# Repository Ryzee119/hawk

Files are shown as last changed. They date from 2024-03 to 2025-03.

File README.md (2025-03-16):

## Hawk - Open Source Xbox Live Communicator

This project is an open source replacement of the [Microsoft Xbox Live Communicator](https://xbox.fandom.com/wiki/Xbox_LIVE_Headset) utilizing modern components and custom open-source firmware.

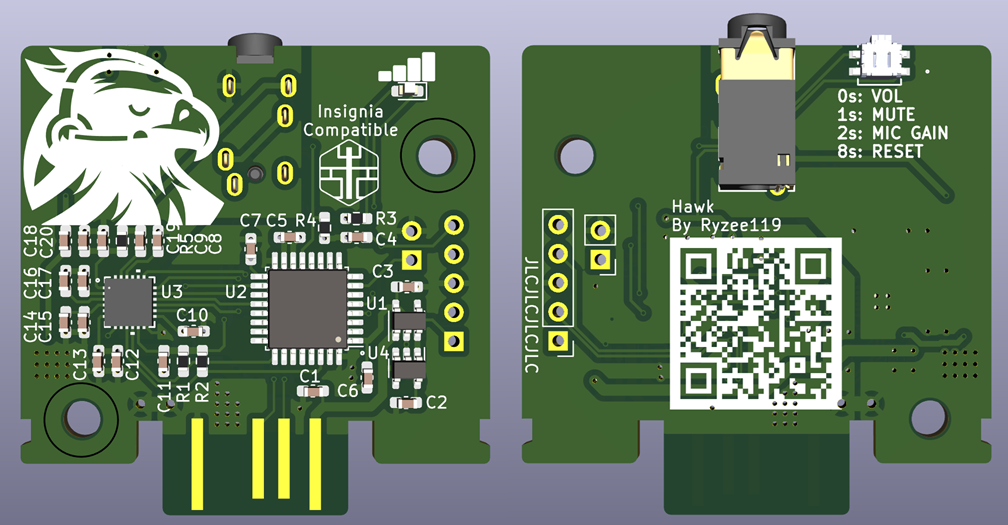
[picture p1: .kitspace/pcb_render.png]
hawk!


It provides feature parity with the original communicator with the following differences:
* A 3.5mm TRRS jack is used to support more generic headsets. (Stereo headsets will output as mono.)
* The volume wheel is replaced with a button. Volume is indicated by LED brightness.

### Usage
* When installing Hawk into your controller, it must be installed in the slot closest to you.
* Press the button to increment the volume. Once maximum volume is reached, it will cycle back to zero.
* Hold the button for 1 second to mute and disable the microphone input (LED will flash at 1Hz).
* Hold the button 2 seconds to enter microphone gain adjustment mode (LED will flash at 4Hz).
* Volume and microphone gain adjustments will be saved internally. You can reset these to default by holding the button down for 8 seconds.

### Assembly
* **When ordering PCB thickness should be 1.2mm!**
* See [Kitspace](https://master.staging.kitspace.dev/Ryzee119/hawk) for BOM, PCB ordering and assembly information.
* See [KiCanvas](https://kicanvas.org/?github=https%3A%2F%2Fgithub.com%2FRyzee119%2Fhawk%2Ftree%2Fmaster%2Fhardware) for schematic view.
* See [Tracespace](https://tracespace.io/view/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) for Gerber view.

### Compilation
* Download and install [Visual Studio Code](https://code.visualstudio.com/).
* Install the [PlatformIO IDE](https://platformio.org/platformio-ide) plugin.
* In Visual Studio Code File > Open Folder... > hawk
* Hit build on the Platform IO toolbar (✓).

### Programming
* [Compile](https://github.com/Ryzee119/hawk?tab=readme-ov-file#compilation) or [Download](https://github.com/Ryzee119/hawk/releases) the pre-built firmware image.
* USB DFU. Connect an xbox controller to your PC, then hold the Hawk button down while inserting it into the controller to enter DFU mode. Your PC should detect this. you can then program with [STM32Cubeprogrammer](https://www.st.com/en/development-tools/stm32cubeprog.html)
* ST-Link interface (5 pin header available on PCB)

### FAQ
* What is the pinout of the headphone jack?
  * Hawk's headphone jack is wired as per [CTIA standard TRRS](https://upload.wikimedia.org/wikipedia/commons/e/ee/3.5mm_TRRS_phone_connector_with_CTIA_standard.png). There is another less common standard called OMTP. This will not work but adapters are available.
* It doesn't fit in my controller slot.
  * PCB should be manufactured with 1.2mm thickness. Most fabrication houses default to 1.6mm so be careful!
* Microphone is really quiet.
  * You can increase the microphone gain above default. Hold the Hawk button down for more than 2 seconds to enter gain adjustment mode. The LED will blink 4 times per second to show it is in the right mode then press the button to increase the gain. Hold for 1 second to exit. If this is still too quiet, you can modify the `MAX_MICROPHONE_GAIN` variable and recompile the code to bump it up even higher.
* Speaker is really quiet
  * Adjust the volume by pressing the button until the LED is at its maximum brightness. Unfortunately, it is already compiled to the maximum allowable by Hawk. If it is still too quiet, your headset's impedance may be too low.
* Does this work on modern controller adapters (ogx360, wingman etc)?
  * Not really, but kind of. To do this, you must connect a USB 1.1 compliant hub to the Xbox player port. Your controller then connects to port 1 of this hub and Hawk to port 2.
* LED just flashes constantly when connected
  * This means the main IC cannot communicate with the audio codec on Hawk. This is likely a soldering issue.
* `Error: Database: There's no active configuration for this device.` when programming.
  * Try an earlier revision of STM32CubeProgrammer. Users have reported some success with `v2.5.0`.

### Attribution
* [Board outline](https://github.com/Zeigren/OXC)
* [EEPROM emulation code](https://github.com/nimaltd/ee)

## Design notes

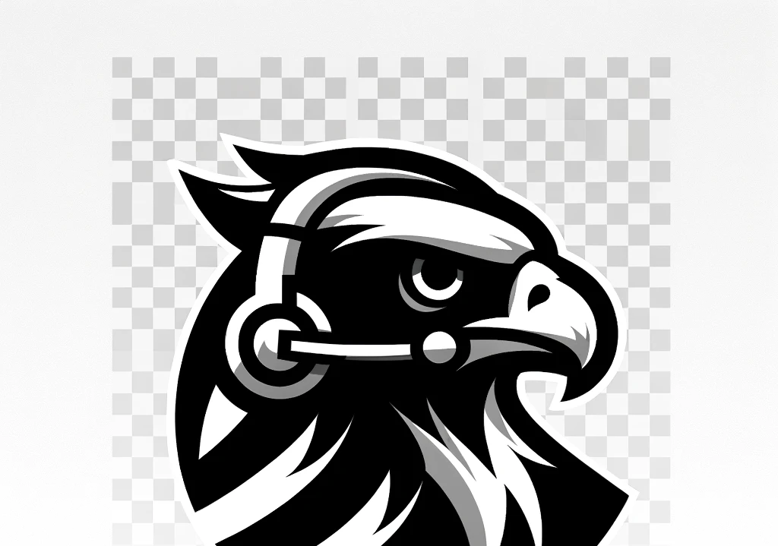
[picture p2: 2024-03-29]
hardware/hawk.bmp

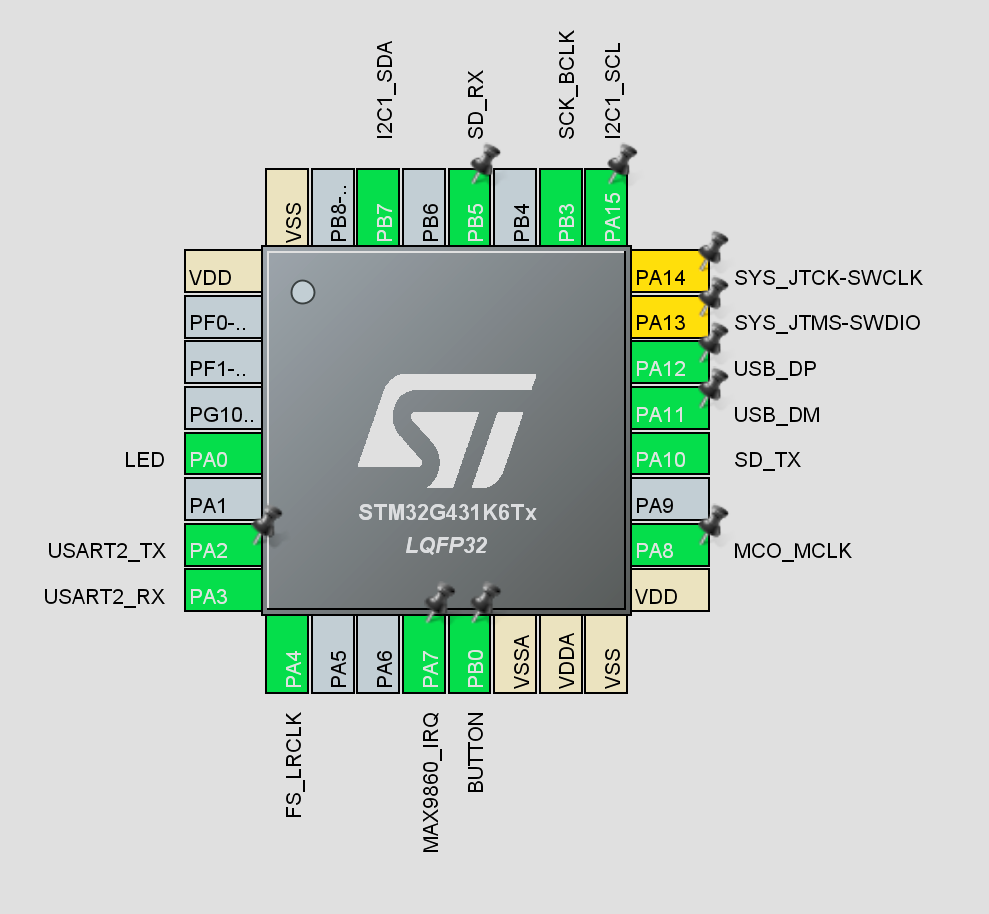
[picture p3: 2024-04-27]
hardware/pinout.png

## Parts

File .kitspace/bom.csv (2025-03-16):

Reference | Qty | Description | Part Number | Manufacturer | Digikey | LCSC
U1 | 1 | IC REG LINEAR 3.3V 300MA SOT23-5 | MIC5504-3.3YM5 | Microchip Technology | 576-4764-1-ND | C3021093
U2 | 1 | IC MCU 32BIT 32KB FLASH 32LQFP | STM32G431K6T6 | STMicroelectronics | 497-STM32G431K6T6-ND | C730097
U3 | 1 | IC CODEC MONO AUD 16BIT 24TQFN | MAX9860ETG+T | Maxim Integrated | MAX9860ETG+TCT-ND | C516787
U4 | 1 | IC REG LINEAR 1.8V 300MA SOT23-5 | MIC5504-1.8YM5 | Microchip Technology | 576-4879-1-ND | C626116
C1, C2, C3, C12, C20 | 5 | CAP CER 10uF 0603 | CAP CER 10uF 0603 | ANY | 311-1448-1-ND | C19702
C4, C5, C6, C7, C13 | 5 | CAP CER 100nF 0603 | CAP CER 100nF 0603 | ANY | 311-1088-1-ND | C30926
C8, C9, C10, C11, C14, C15, C16, C17, C18, C19 | 10 | CAP CER 1uF 0603 | CAP CER 1uF 0603 | ANY | 311-1446-1-ND | C15849
R1, R2, R4, R5 | 4 | RES SMD 1.5K OHM 1% 1/10W 0603 | RES SMD 1.5K OHM 1% 1/10W 0603 | ANY | 118-CR0603-FX-1501ELFCT-ND | C114668
R3 | 1 | RES SMD 150 OHM 1% 1/10W 0603 | RES SMD 150 OHM 1% 1/10W 0603 | ANY | 118-CR0603-FX-1500ELFCT-ND | C114608
D1 | 1 | LED 2V 20MA 0603 | LED 2V 20MA 0603 | ANY | 3147-B1911PG--20D000514U1930CT-ND | C5123548
J3 | 1 | CONN JACK TRRS 3.5MM | 54-00298 | Tensility International Corp | 839-54-00298CT-ND | C707261
SW1 | 1 | SWITCH TACTILE SPST-NO MOM | EVQ-P7J01P | Panasonic Electronic Components | P16767CT-ND | C2828254

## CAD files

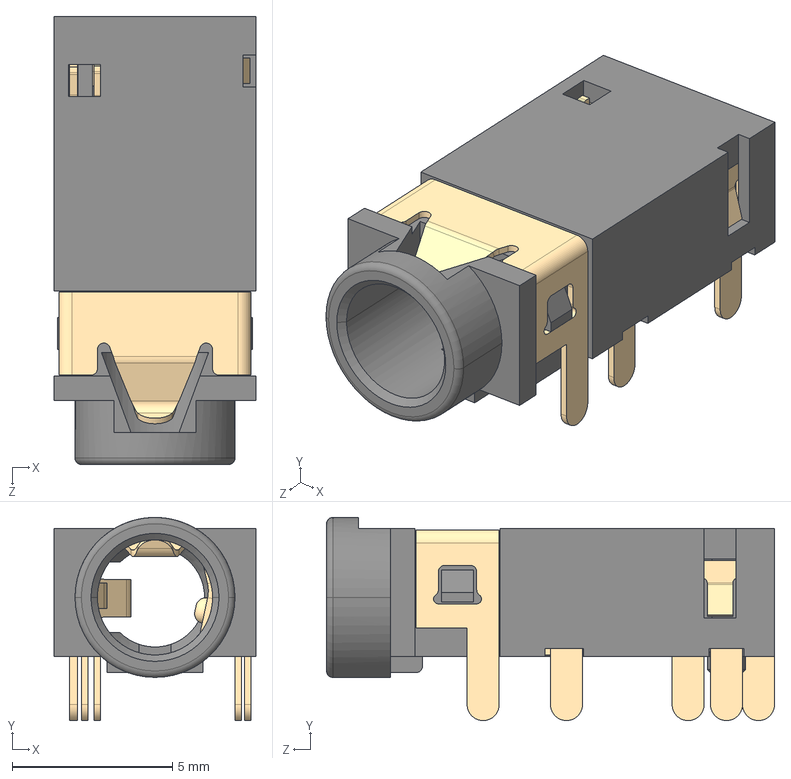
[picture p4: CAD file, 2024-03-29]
hardware/parts/54-00298/54-00298.step
6.30 x 6.35 x 14.0 mm

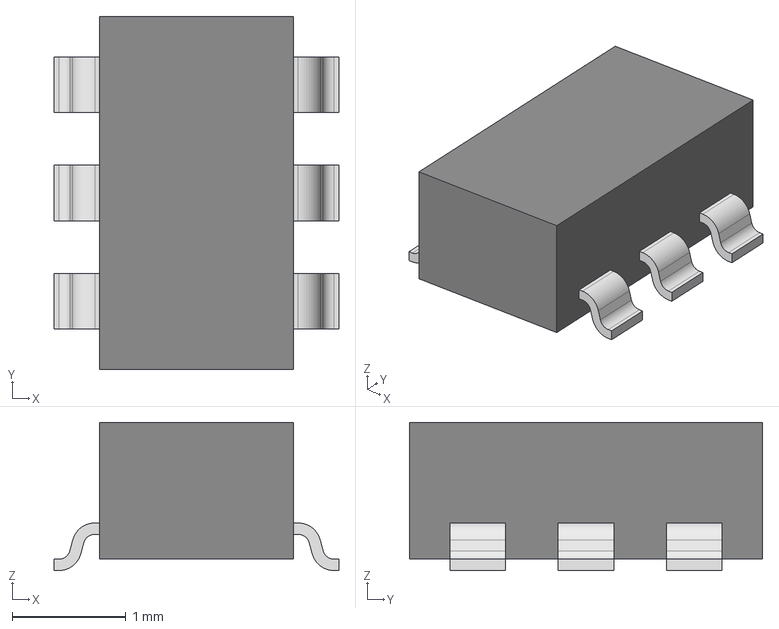
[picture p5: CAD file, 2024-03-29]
hardware/parts/AP7312_1833W6_7/SOT26_DIO.step
2.50 x 3.10 x 1.30 mm

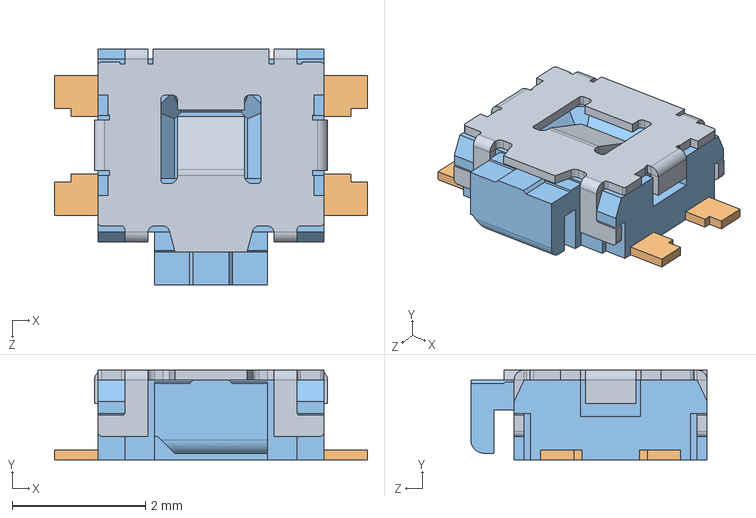
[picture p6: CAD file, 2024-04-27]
hardware/parts/EVQ-P7L01P/EVQ-P7L01P.step
4.70 x 1.35 x 3.55 mm

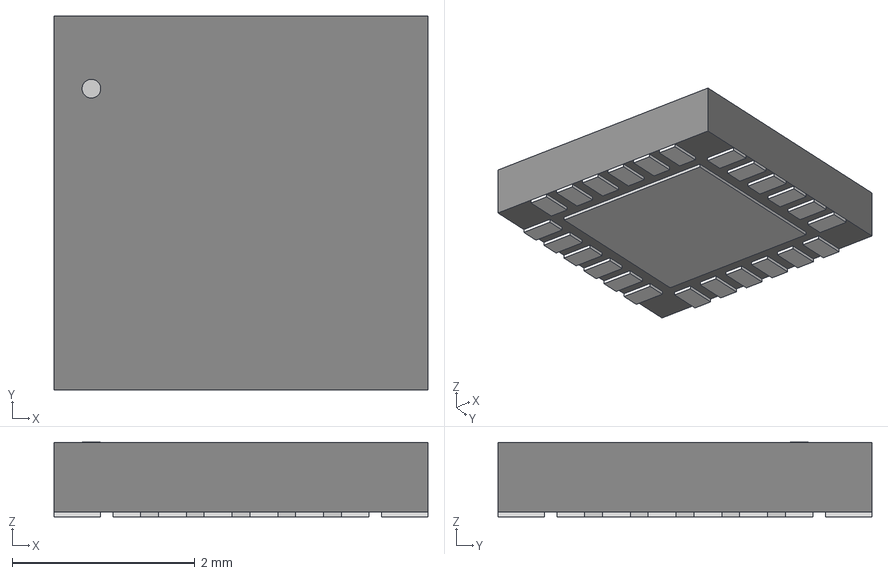
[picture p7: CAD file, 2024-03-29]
hardware/parts/MAX9860ETG_T/21-0139I_T2444-4_MXM.step
4.09 x 4.09 x 0.815 mm

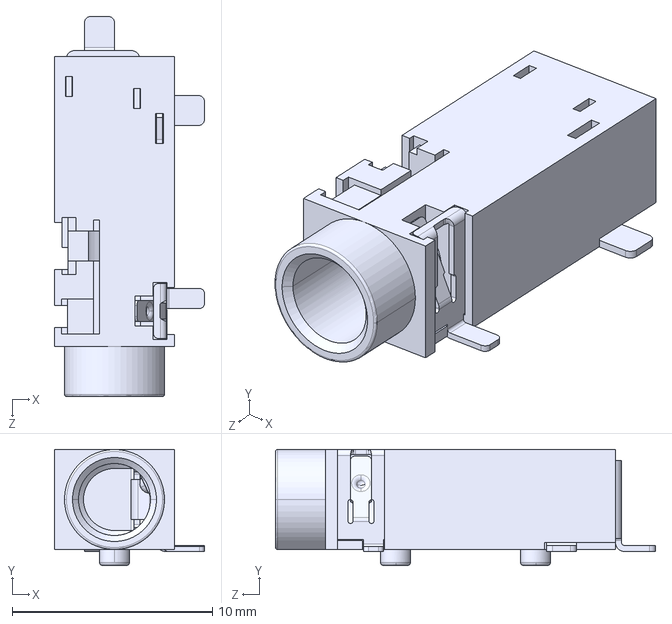
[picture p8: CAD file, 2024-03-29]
hardware/parts/MJ_3523_SMT_TR/CUI_DEVICES_MJ-3523-SMT-TR.step
7.50 x 5.80 x 19.0 mm

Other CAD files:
hardware/parts/EVQ_P7A01P/EVQ-P7A01P.step

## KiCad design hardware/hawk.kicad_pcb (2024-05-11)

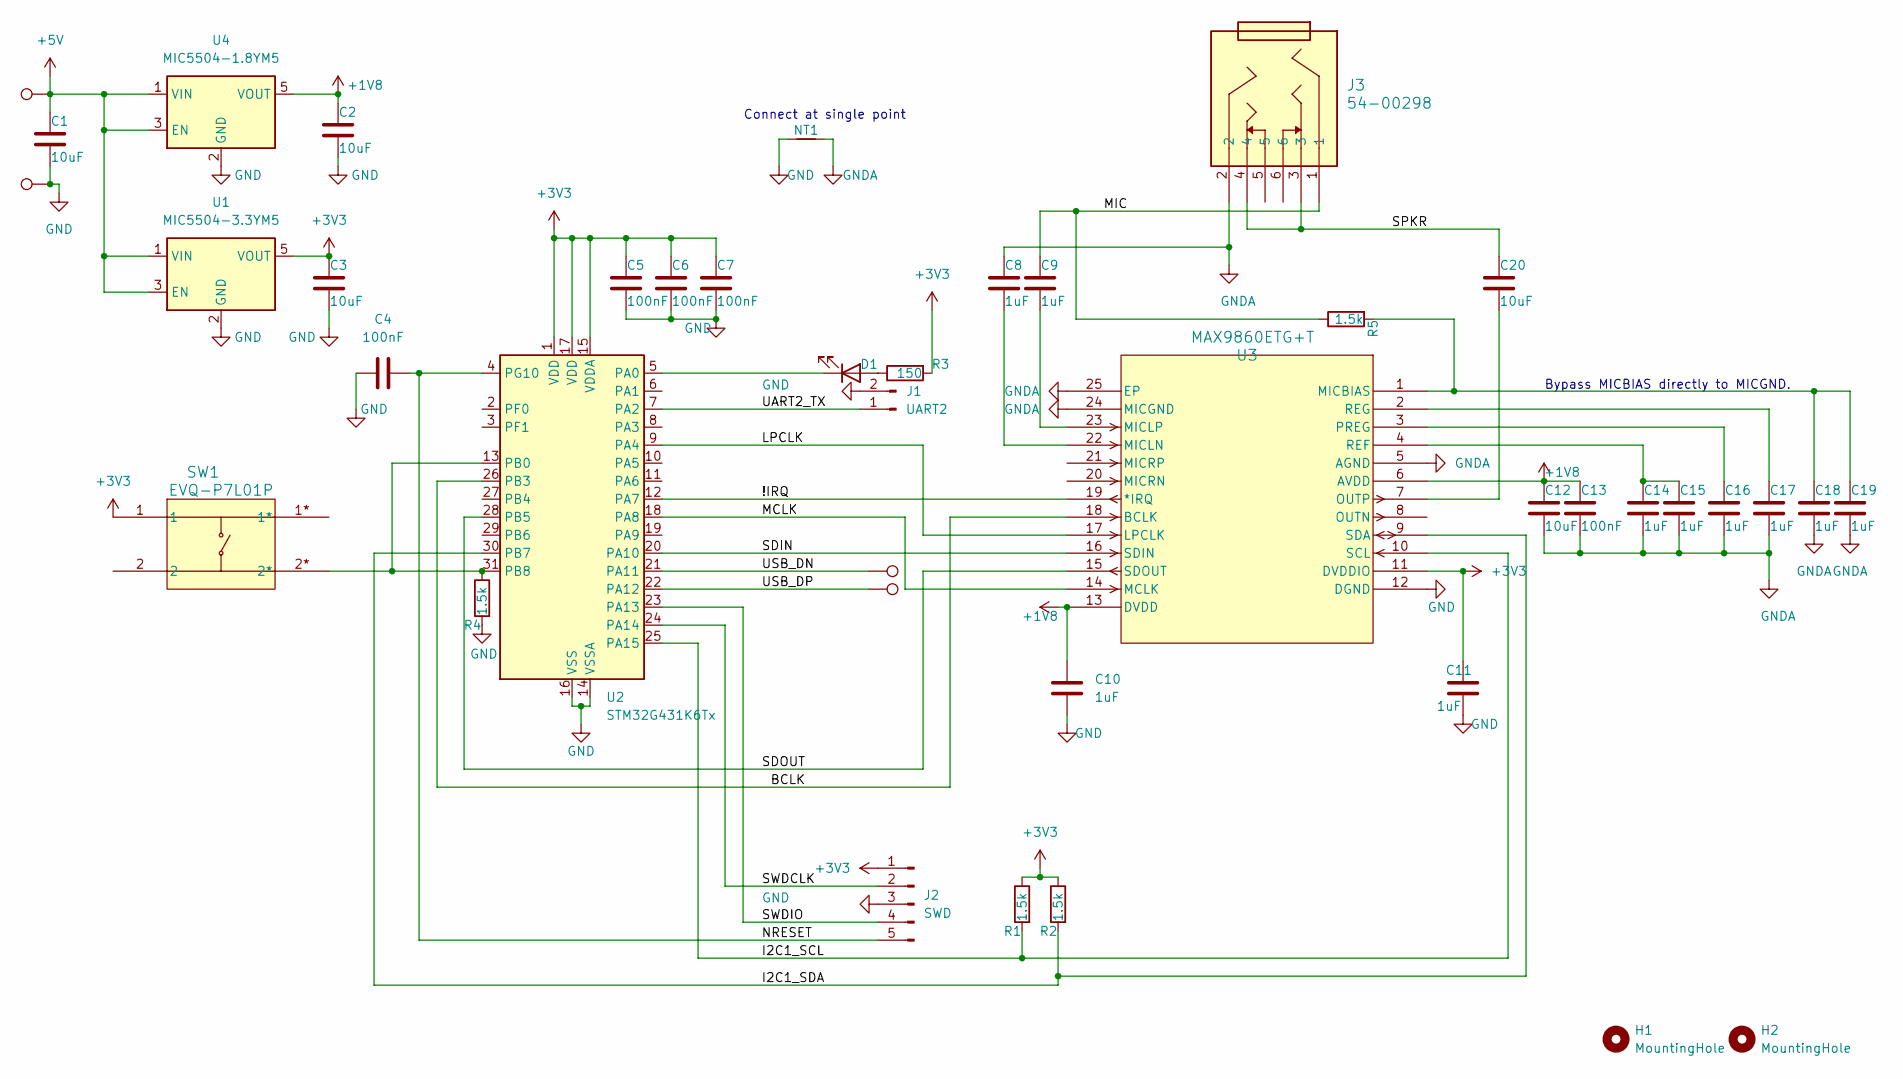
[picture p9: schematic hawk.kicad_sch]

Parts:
C1, C2, C3, C12, C20: 10uF; C_0603_1608Metric_Pad1.08x0.95mm_HandSolder
C4, C5, C6, C7, C13: 100nF; C_0603_1608Metric_Pad1.08x0.95mm_HandSolder
C8, C9, C10, C11, C14, C15, C16, C17, C18, C19: 1uF; C_0603_1608Metric_Pad1.08x0.95mm_HandSolder
D1: LED; LED_0603_1608Metric_Pad1.05x0.95mm_HandSolder
H1, H2: MountingHole; MountingHole_3.2mm_M3
J1: UART2; PinHeader_1x02_P2.54mm_Vertical
J2: SWD; PinHeader_1x05_P2.54mm_Vertical
J3: 54-00298
NT1: NetTie_2; NetTie-2_THT_Pad1.0mm
R1, R2, R4, R5: 1.5k; R_0603_1608Metric_Pad0.98x0.95mm_HandSolder
R3: 150; R_0603_1608Metric_Pad0.98x0.95mm_HandSolder
SW1: EVQ-P7L01P; EVQ_P7_PAN
TP1: USB_5V; TestPoint_Pad_1.0x1.0mm
TP2: USB_GND; TestPoint_Pad_1.0x1.0mm
TP3: USB_DM; TestPoint_Pad_1.0x1.0mm
TP4: USB_DP; TestPoint_Pad_1.0x1.0mm
U1: MIC5504-3.3YM5; SOT-23-5
U2: STM32G431K6Tx; LQFP-32_7x7mm_P0.8mm
U3: MAX9860ETG+T; 21-0139I_T2444-4_MXM
U4: MIC5504-1.8YM5; SOT-23-5

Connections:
+1V8: C2.1, C10.1, C12.1, C13.1, U3.6 (AVDD), U3.13 (DVDD), U4.5 (VOUT)
+3V3: C3.1, C5.1, C6.1, C7.1, C11.1, J2.1, R1.1, R2.1, R3.2, SW1.1, U1.5 (VOUT), U2.1 (VDD), U2.15 (VDDA), U2.17 (VDD), U3.11 (DVDDIO)
+5V: C1.1, TP1.1, U1.1 (VIN), U1.3 (EN), U4.1 (VIN), U4.3 (EN)
/!IRQ: U2.12 (PA7), U3.19 (*IRQ)
/BCLK: U2.26 (PB3), U3.18 (BCLK)
/I2C1_SCL: R1.2, U2.25 (PA15), U3.10 (SCL)
/I2C1_SDA: R2.2, U2.30 (PB7), U3.9 (SDA)
/LPCLK: U2.9 (PA4), U3.17 (LPCLK)
/MCLK: U2.18 (PA8), U3.14 (MCLK)
/MIC: C9.1, J3.1, R5.1
/NRESET: C4.1, J2.5, U2.4 (PG10)
/SDIN: U2.20 (PA10), U3.16 (SDIN)
/SDOUT: U2.28 (PB5), U3.15 (SDOUT)
/SPKR: C20.1, J3.3, J3.4
/SWDCLK: J2.2, U2.24 (PA14)
/SWDIO: J2.4, U2.23 (PA13)
/UART2_TX: J1.1, U2.7 (PA2)
/USB_DN: TP3.1, U2.21 (PA11)
/USB_DP: TP4.1, U2.22 (PA12)
GND: C1.2, C2.2, C3.2, C4.2, C5.2, C6.2, C7.2, C10.2, C11.2, J1.2, J2.3, NT1.1, R4.2, TP2.1, U1.2 (GND), U2.14 (VSSA), U2.16 (VSS), U2.32 (VSS), U3.12 (DGND), U4.2 (GND)
GNDA: C8.1, C12.2, C13.2, C14.2, C15.2, C16.2, C17.2, C18.2, C19.2, J3.2, NT1.2, U3.5 (AGND), U3.24 (MICGND), U3.25 (EP)
unnamed: D1.2 (A), R3.1
unnamed: D1.1 (K), U2.5 (PA0)
unnamed: R4.1, SW1.2*, U2.13 (PB0), U2.31 (PB8)
unnamed: C18.1, C19.1, R5.2, U3.1 (MICBIAS)
unnamed: C8.2, U3.22 (MICLN)
unnamed: C9.2, U3.23 (MICLP)
unnamed: C20.2, U3.7 (OUTP)
unnamed: C16.1, U3.3 (PREG)
unnamed: C14.1, C15.1, U3.4 (REF)
unnamed: C17.1, U3.2 (REG)

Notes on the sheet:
Connect at single point
Bypass MICBIAS directly to MICGND.

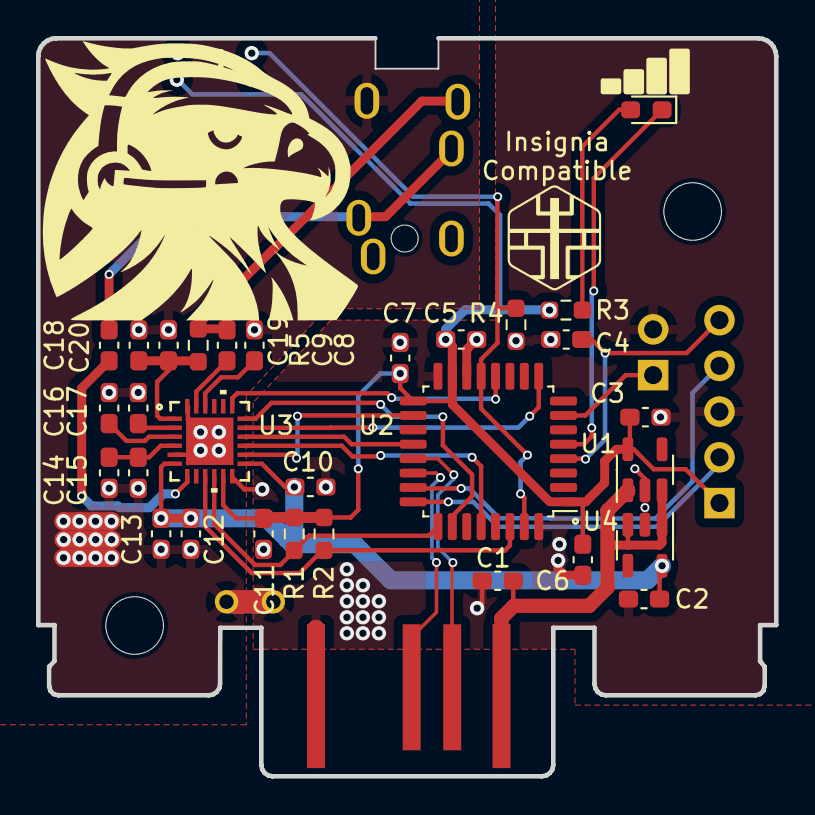
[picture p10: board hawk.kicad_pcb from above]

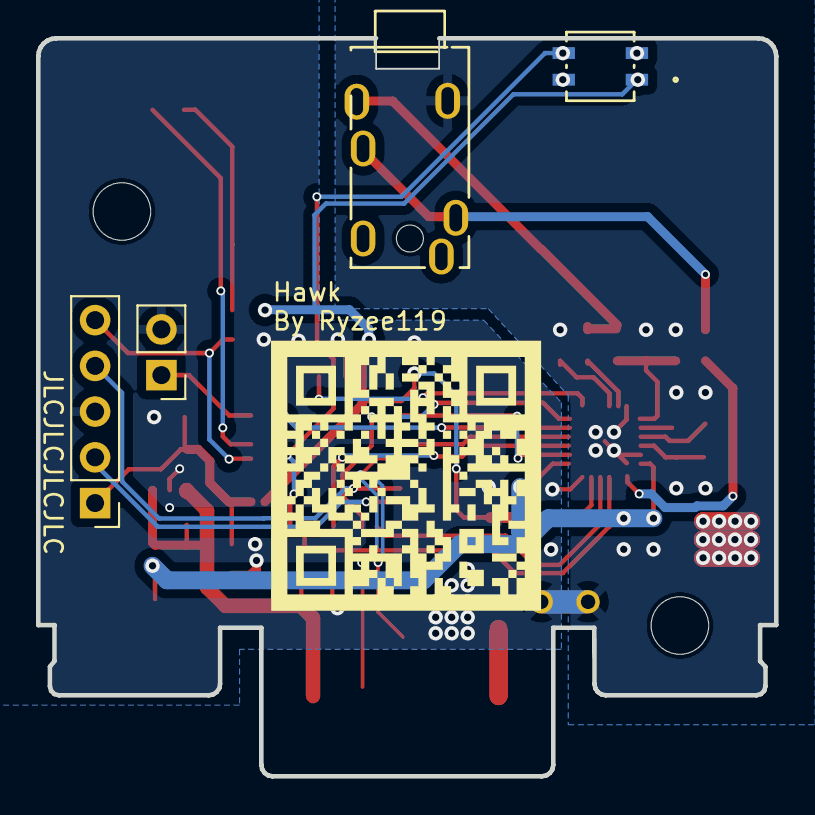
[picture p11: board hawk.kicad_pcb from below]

Board: 2 copper layers, 41.0 x 41.0 mm, 41 parts (4 on the bottom side), 31 nets.

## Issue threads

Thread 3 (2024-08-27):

Feature request

remojansen, 2024-08-27:
Hi, I saw this and wondered if the following would be possible:

## Bluetooth-capable version

Create a new version that includes a Bluetooth transceiver so wireless headphones are compatible. I guess that you will also require a small LCD to list the Bluetooth devices that have been detected. I don't see why this could not work with factory models.

## Game audio capable (moded-xbox only)

The OG Xbox communicator only plays party chat audio. However, could the BIOS or OS be configured to route game audio to the controller? It would be great to listen to both party and game audio via headphones. I'm not sure if it is possible at a hardware level, but for example, the game Manhunt played some in-game sound effects through the communicator. So, I guess that it should be possible (it might require lowering the audio quality).

Thanks for your excellent work!

Ryzee119, 2024-08-27:
Closing as not really an issue and out of the scope of this project.

I'm sure it is all possible. Maybe you or someone else could give it a shot

Closed 2024-08-27.

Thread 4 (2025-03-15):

Update BOM: SW1 Without Boss

nightowl3090, 2025-03-15:
BOM lists part number EVQ-P7L01P for SW1 which have mounting alignment pegs. But no tooling holes are present on the PCB in that location.

Board needs to be modified to accommodate alignment guides or alternative part number EVQ-P7J01P (without boss) should be used.

PCB manufacturer recommends vias be resin filled or removed at SW1.

Ryzee119, 2025-03-16:
what the.. howd that happen. I will update the BOM. Thanks

Ryzee119, 2025-03-16:
Fix in https://github.com/Ryzee119/hawk/commit/18cb86d6f88a00b7279da5ea105ce131e3b48ac9.

Thanks for pointing this out. Apologies for the issues at manufacture

Closed 2025-03-16.

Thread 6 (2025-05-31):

About 3D Printed Enclosure for the Project

draakania, 2025-05-31:
Hi,

I just wanted to check if you’ve designed a 3D printed enclosure for the project?

Best regards,

Ryzee119, 2025-05-31:
I have not developed any enclosure. I don't personally plan to for this project

draakania, 2025-06-01:
Thanks you !

EmSixTeen, 2025-06-01:
I don't want to clog this up, but just want to add that I'd love a print file if anyone were to create one.

draakania, 2025-06-01:
After receiving the material, I’ll create one myself. I just wanted to check if someone had already made one. I’ll be happy to share it with you once it’s done

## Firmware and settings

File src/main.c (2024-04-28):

// SPDX-License-Identifier: MIT
// SPDX-FileCopyrightText: 2024 Ryan Wendland

// i2S Audio codec to USB bridge.
// USB is coded to simulate an Xbox Live Communicator for the Original Xbox
// I2S is generated with STMs SAI interface as a slave device. The audio codex is a MAX9860 and is the master device.
// The STM provides a master clock to the MAX9860 using MCO and the MAX9860 provides the bit clock and frame sync back
// to the STM. The master clock is provided to the MAX9860 by STM's HSI48 which is automatically adjusted to match the
// USB clock using the clock recovery system. This eliminates the need for a crystal or other clock source and prevents
// drift between the USB clock and onboard clocks. All the I2s audio processing is circular DMA/interrupt driven and is
// pushed into a FIFO buffer for microphone data, and read from a FIFO buffer for speaker data. The USB interface reads
// from the FIFO for microphone data and writes to the FIFO for speaker data. This is all interrupt driven.

#include "main.h"
#include "eeprom_emulation/ee.h"
#include "max9860/max9860.h"
#include "usbd/usb_device.h"
#include "fifo.h"

#define RAM_FUNC __attribute__((section(".RamFunc")))
#define MCO_FREQ 12000000UL  // 48Mhz / 4 See SystemClock_Config

void SystemClock_Config(void);
static void MX_GPIO_Init(void);
static void MX_DMA_Init(void);
static void MX_I2C1_Init(void);
static void MX_SAI1_Init(void);
static void MX_USART2_UART_Init(void);
static void MX_TIM2_Init(void);
static void set_led_brightness(uint8_t percent);
static void start_new_audio_stream(uint32_t sample_rate);

// Peripheral handles
I2C_HandleTypeDef hi2c1;
SAI_HandleTypeDef hsai_BlockA1; // Speaker
SAI_HandleTypeDef hsai_BlockB1; // Microphone
DMA_HandleTypeDef hdma_sai1_a;
DMA_HandleTypeDef hdma_sai1_b;
TIM_HandleTypeDef htim2;
UART_HandleTypeDef huart2;

// Codec
static max9860_device_t max9860;
static uint32_t pending_sample_rate_change = 0;
static uint8_t pending_agc_change = 0;
static uint8_t microphone_muted = 0;

// Non volatile storage
#define HAWK_MAGIC (0x4841574B)
typedef struct {
    uint32_t magic;
    int8_t volume;
    uint8_t mic_gain;
    uint8_t reserved[2];
} hawk_storage_t;
hawk_storage_t ee;
uint32_t ee_dirty = 0;

// Data fifos for linking USB and SAI I2S
#define FIFO_BUFF_SZ (48 * 8)
static fifo_t fifo_speaker;
static fifo_t fifo_mic;
static uint8_t fifo_speaker_buffer[FIFO_BUFF_SZ];
static uint8_t fifo_mic_buffer[FIFO_BUFF_SZ];

// UART FIFO
static uint8_t uart_fifo[256];
static uint32_t uart_fifo_head = 0, uart_fifo_tail = 0;
void io_puts(const char *s, void *ctx) {
    while (*s) {
        uart_fifo[uart_fifo_tail] = *s++;
        uart_fifo_tail = (uart_fifo_tail + 1) % sizeof(uart_fifo);
    }
}

// Circular DMA buffers for SAI TX and RX
#define SAI_DMA_BUFFER_BYTES (FIFO_BUFF_SZ)
static uint8_t tx_dma_buffer[SAI_DMA_BUFFER_BYTES] __attribute__((aligned(4)));
static uint8_t rx_dma_buffer[SAI_DMA_BUFFER_BYTES] __attribute__((aligned(4)));

// LED
static uint32_t led_rate = 0;
static uint8_t led_brightness = 0;

void (*SysMemBootJump)(void);

int main(void) {
    HAL_Init();
    SystemClock_Config();

    // Initialize all configured peripherals
    MX_GPIO_Init();
    MX_DMA_Init();
    MX_USART2_UART_Init();
    MX_I2C1_Init();
    MX_SAI1_Init();
    MX_TIM2_Init();
    MX_USB_Device_Init();

    io_puts("HAWK!\n", NULL);

    // Emulated EEPROM
    EE_Init(&ee, sizeof(ee));
    EE_Read();
    if (ee.magic != HAWK_MAGIC) {
        io_puts("EEPROM RESET\n", NULL);
        memset(&ee, 0, sizeof(ee));
        ee.magic = HAWK_MAGIC;
        ee.volume = DEFAULT_SPEAKER_GAIN;
        ee.mic_gain = DEFAULT_MICROPHONE_GAIN;
        EE_Write(true);
    }

    if (max9860_init(&max9860, &hi2c1, MCO_FREQ) == false) {
        io_puts("MAX9860 INIT FAILED\n", NULL);
        while (1) {
            set_led_brightness(100);
            HAL_Delay(100);
            set_led_brightness(0);
            HAL_Delay(100);
        }
    }

    // Setup audio codec
    max9860_set_volume(&max9860, 20);
    max9860_mic_agc_enable(&max9860);
    max9860_start(&max9860);
    led_brightness = (((ee.volume - MIN_SPEAKER_GAIN) * 100) / (MAX_SPEAKER_GAIN - MIN_SPEAKER_GAIN));
    led_rate = 0;

    // Prepare FIFOs
    fifo_init(&fifo_speaker, fifo_speaker_buffer, sizeof(fifo_speaker_buffer));
    fifo_init(&fifo_mic, fifo_mic_buffer, sizeof(fifo_mic_buffer));

    // Start the I2s Interface DMA circular buffer.
    start_new_audio_stream(DEFAULT_SAMPLE_RATE);

    while (1) {
        uint32_t current_tick = HAL_GetTick();

        // Process and clear max9860 IRQs
        if (max9860.has_irq) {
            max9860.has_irq = false;
            // Read and clear the status
            if (max9860_get_irq_status(&max9860)) {
                io_puts("IRQ: ", NULL);
                io_puts((max9860.INTRSTATUS & MAX9860_CLD) ? "CLD " : "", NULL);
                io_puts((max9860.INTRSTATUS & MAX9860_SLD) ? "SLD " : "", NULL);
                io_puts((max9860.INTRSTATUS & MAX9860_ULK) ? "ULK " : "", NULL);
                io_puts("\n", NULL);
            }
        }

        // Handle a sample rate change
        if (pending_sample_rate_change) {
            io_puts("SR: ", NULL);
            io_puts((pending_sample_rate_change == 8000)    ? "8k"
                    : (pending_sample_rate_change == 11025) ? "11k"
                    : (pending_sample_rate_change == 16000) ? "16k"
                    : (pending_sample_rate_change == 22050) ? "22k"
                    : (pending_sample_rate_change == 24000) ? "24k"
                                                            : "???",
                    NULL);
            io_puts("\n", NULL);
            start_new_audio_stream(pending_sample_rate_change);
            pending_sample_rate_change = 0;
        }

        // Handle auto gain control toggle
        if (pending_agc_change & 0x80) {
            uint8_t agc = pending_agc_change & 0x7F;
            pending_agc_change = 0;
            io_puts("AGC: ", NULL);
            io_puts(agc ? "ON\n" : "OFF\n", NULL);
            if (agc) {
                max9860_mic_agc_enable(&max9860);
            } else {
                max9860_mic_agc_disable(&max9860, DEFAULT_MICROPHONE_GAIN);
                max9860_set_mic_gain(&max9860, ee.mic_gain);
            }
            pending_agc_change = 0;
        }

        // Flush UART fifo
        if (uart_fifo_head != uart_fifo_tail) {
            uint32_t len = (uart_fifo_head < uart_fifo_tail) ? (uart_fifo_tail - uart_fifo_head)
                                                             : (sizeof(uart_fifo) - uart_fifo_head);
            HAL_UART_Transmit(&huart2, &uart_fifo[uart_fifo_head], len, 0xFFFF);
            uart_fifo_head = (uart_fifo_head + len) % sizeof(uart_fifo);
        }

        // Prevent thrashing emulated eeprom. Only write if dirty and some period has passed
        if (ee_dirty && (HAL_GetTick() - ee_dirty) > 10000) {
            EE_Write(true);
            ee_dirty = 0;
            io_puts("EEPROM WRITTEN\n", NULL);
        }

        // Handle flashing of the LED
        static uint32_t led_tick = 0;
        static uint32_t tgl = 0;
        uint32_t led_held = current_tick - led_tick;
        if (led_rate) {
            if (led_held > led_rate) {
                led_tick = current_tick;
                set_led_brightness((tgl ^= 1) ? led_brightness : 0);
            }
        } else {
            set_led_brightness(led_brightness);
        }

        // The button has 4 modes. Normal, Mute, Mic Gain, and EEPROM Reset
        // Normal mode adjusts the volume. The LED brightness is set to the volume level.
        // Mute does not transfer any microphone information. This is indicated a slow flash of the LED.
        // Mic Gain mode makes the button adjust the microphone gain. This is indicated by a medium flash of the LED.
        // EEPROM Reset mode resets the EEPROM to defaults this is indicated by a fast flash of the LED.
        typedef enum { NORMAL_MODE, MUTE_MODE, MIC_GAIN_MODE, EEPROM_RESET_MODE } button_mode_t;
        static button_mode_t button_mode = NORMAL_MODE;
        static uint8_t last_button_state = 0;
        static uint32_t button_pressed_tick = 0;

        uint8_t button_state = HAL_GPIO_ReadPin(BUTTON_GPIO_Port, BUTTON_Pin);
        if (button_state && button_state != last_button_state) {
            button_pressed_tick = current_tick;
        }

        if (!button_state && button_state != last_button_state) {
            if (current_tick - button_pressed_tick > 8000) {
                io_puts("EEPROM RESET\n", NULL);
                button_mode = EEPROM_RESET_MODE;
                led_rate = 100;
                led_brightness = 100;
                memset(&ee, 0, sizeof(ee));
                ee.magic = HAWK_MAGIC;
                ee.volume = DEFAULT_SPEAKER_GAIN;
                ee.mic_gain = DEFAULT_MICROPHONE_GAIN;
                EE_Write(true);

            } else if (current_tick - button_pressed_tick > 2000) {
                io_puts("MIC GAIN\n", NULL);
                button_mode = (button_mode == MIC_GAIN_MODE) ? NORMAL_MODE : MIC_GAIN_MODE;
                microphone_muted = 0;
                led_rate = 250;
                led_brightness =
                    (((ee.mic_gain - MIN_MICROPHONE_GAIN) * 100) / (MAX_MICROPHONE_GAIN - MIN_MICROPHONE_GAIN));

            } else if (current_tick - button_pressed_tick > 500) {
                if (button_mode != MIC_GAIN_MODE) {
                    io_puts("MUTE\n", NULL);
                    button_mode = MUTE_MODE;
                    led_rate = 1000;
                    led_brightness = 50;
                    microphone_muted = 1;
                } else {
                    button_mode = NORMAL_MODE;
                    led_rate = 0;
                    led_brightness = (((ee.volume - MIN_SPEAKER_GAIN) * 100) / (MAX_SPEAKER_GAIN - MIN_SPEAKER_GAIN));
                }

            } else if (current_tick - button_pressed_tick > 50) {
                if (button_mode == NORMAL_MODE) {
                    ee.volume += SPEAKER_INCREMEMENT;
                    // When it reaches max, one more press is no change, 2nd press resets to zero
                    if (ee.volume > (MAX_SPEAKER_GAIN + SPEAKER_INCREMEMENT)) {
                        ee.volume = MIN_SPEAKER_GAIN;
                    }
                    max9860_set_volume(&max9860, ee.volume);
                    led_brightness = (((ee.volume - MIN_SPEAKER_GAIN) * 100) / (MAX_SPEAKER_GAIN - MIN_SPEAKER_GAIN));
                    ee_dirty = HAL_GetTick();

                } else if (button_mode == MIC_GAIN_MODE) {
                    ee.mic_gain += MICROPHONE_INCREMEMENT;
                    // When it reaches max, one more press is no change, 2nd press resets to zero
                    if (ee.mic_gain > (MAX_MICROPHONE_GAIN + MICROPHONE_INCREMEMENT)) {
                        ee.mic_gain = MIN_MICROPHONE_GAIN;
                    }
                    max9860_set_mic_gain(&max9860, ee.mic_gain);
                    led_brightness =
                        (((ee.mic_gain - MIN_MICROPHONE_GAIN) * 100) / (MAX_MICROPHONE_GAIN - MIN_MICROPHONE_GAIN));
                    ee_dirty = HAL_GetTick();

                } else {
                    microphone_muted = 0;
                    led_rate = 0;
                    button_mode = NORMAL_MODE;
                }
            }
        }
        last_button_state = button_state;
    }
}

static inline void set_led_brightness(uint8_t percent) {
    __HAL_TIM_SET_COMPARE(&htim2, TIM_CHANNEL_1, percent);
}

void start_new_audio_stream(uint32_t sample_rate) {
    HAL_SAI_DMAStop(&hsai_BlockA1);
    HAL_SAI_DMAStop(&hsai_BlockB1);

    max9860_set_sample_rate(&max9860, sample_rate);

    memset(tx_dma_buffer, 0, SAI_DMA_BUFFER_BYTES);
    memset(rx_dma_buffer, 0, SAI_DMA_BUFFER_BYTES);

    HAL_SAI_Transmit_DMA(&hsai_BlockA1, tx_dma_buffer, SAI_DMA_BUFFER_BYTES / 2);
    HAL_SAI_Receive_DMA(&hsai_BlockB1, rx_dma_buffer, SAI_DMA_BUFFER_BYTES / 2);
}

// SAI uses a circular DMA. This has two call backs. One when half the buffer is complete and another when fully
// complete We use these callbacks to refill the buffer with data from the FIFO or push data to the FIFO
RAM_FUNC void HAL_SAI_TxHalfCpltCallback(SAI_HandleTypeDef *hsai) {
    fifo_read(&fifo_speaker, &tx_dma_buffer[0], SAI_DMA_BUFFER_BYTES / 2);
}

RAM_FUNC void HAL_SAI_TxCpltCallback(SAI_HandleTypeDef *hsai) {
    fifo_read(&fifo_speaker, &tx_dma_buffer[SAI_DMA_BUFFER_BYTES / 2], SAI_DMA_BUFFER_BYTES / 2);
}

RAM_FUNC void HAL_SAI_RxHalfCpltCallback(SAI_HandleTypeDef *hsai) {
    if (!microphone_muted)
        fifo_write(&fifo_mic, &rx_dma_buffer[0], SAI_DMA_BUFFER_BYTES / 2);
}

RAM_FUNC void HAL_SAI_RxCpltCallback(SAI_HandleTypeDef *hsai) {
    if (!microphone_muted)
        fifo_write(&fifo_mic, &rx_dma_buffer[SAI_DMA_BUFFER_BYTES / 2], SAI_DMA_BUFFER_BYTES / 2);
}

RAM_FUNC void USBD_XBLC_Data_Received(USBD_HandleTypeDef *pdev, uint8_t *data, uint16_t sz) {
    fifo_write(&fifo_speaker, data, sz);
}

RAM_FUNC void USBD_XBLC_Get_Data(USBD_HandleTypeDef *pdev, uint8_t *data, uint16_t sz) {
    fifo_read(&fifo_mic, data, sz);
}

RAM_FUNC void USBD_XBLC_Sample_Rate_Changed(USBD_HandleTypeDef *pdev, uint32_t sample_rate) {
    pending_sample_rate_change = sample_rate;
}

RAM_FUNC void USBD_XBLC_AGC_Changed(USBD_HandleTypeDef *pdev, uint8_t value) {
    pending_agc_change = 0x80 | value;
}

void HAL_GPIO_EXTI_Callback(uint16_t GPIO_Pin) {
    if (GPIO_Pin == MAX9860_IRQ_Pin) {
        max9860.has_irq = true;
    }
}

void SystemClock_Config(void) {
    RCC_OscInitTypeDef RCC_OscInitStruct = {0};
    RCC_ClkInitTypeDef RCC_ClkInitStruct = {0};
    RCC_CRSInitTypeDef pInit = {0};

    HAL_PWREx_ControlVoltageScaling(PWR_REGULATOR_VOLTAGE_SCALE1);

    // PLL setup quite low only at 16Mhz. All hardware driven so we dont need much and saves power
    RCC_OscInitStruct.OscillatorType = RCC_OSCILLATORTYPE_HSI | RCC_OSCILLATORTYPE_HSI48;
    RCC_OscInitStruct.HSIState = RCC_HSI_ON;
    RCC_OscInitStruct.HSICalibrationValue = RCC_HSICALIBRATION_DEFAULT;
    RCC_OscInitStruct.HSI48State = RCC_HSI48_ON;
    RCC_OscInitStruct.PLL.PLLState = RCC_PLL_ON;
    RCC_OscInitStruct.PLL.PLLSource = RCC_PLLSOURCE_HSI;
    RCC_OscInitStruct.PLL.PLLM = RCC_PLLM_DIV1;
    RCC_OscInitStruct.PLL.PLLN = 8;
    RCC_OscInitStruct.PLL.PLLP = RCC_PLLP_DIV2;
    RCC_OscInitStruct.PLL.PLLQ = RCC_PLLQ_DIV2;
    RCC_OscInitStruct.PLL.PLLR = RCC_PLLR_DIV8;
    if (HAL_RCC_OscConfig(&RCC_OscInitStruct) != HAL_OK) {
        Error_Handler();
    }

    RCC_ClkInitStruct.ClockType = RCC_CLOCKTYPE_HCLK | RCC_CLOCKTYPE_SYSCLK | RCC_CLOCKTYPE_PCLK1 | RCC_CLOCKTYPE_PCLK2;
    RCC_ClkInitStruct.SYSCLKSource = RCC_SYSCLKSOURCE_PLLCLK;
    RCC_ClkInitStruct.AHBCLKDivider = RCC_SYSCLK_DIV1;
    RCC_ClkInitStruct.APB1CLKDivider = RCC_HCLK_DIV1;
    RCC_ClkInitStruct.APB2CLKDivider = RCC_HCLK_DIV1;

    if (HAL_RCC_ClockConfig(&RCC_ClkInitStruct, FLASH_LATENCY_0) != HAL_OK) {
        Error_Handler();
    }

    HAL_RCC_MCOConfig(RCC_MCO1, RCC_MCO1SOURCE_HSI48, RCC_MCODIV_4);

    __HAL_RCC_CRS_CLK_ENABLE();
    pInit.Prescaler = RCC_CRS_SYNC_DIV1;
    pInit.Source = RCC_CRS_SYNC_SOURCE_USB;
    pInit.Polarity = RCC_CRS_SYNC_POLARITY_RISING;
    pInit.ReloadValue = __HAL_RCC_CRS_RELOADVALUE_CALCULATE(48000000, 1000);
    pInit.ErrorLimitValue = 34;
    pInit.HSI48CalibrationValue = 32;

    HAL_RCCEx_CRSConfig(&pInit);
}

static void MX_I2C1_Init(void) {
    hi2c1.Instance = I2C1;
    hi2c1.Init.Timing = 0x00303D5B;
    hi2c1.Init.OwnAddress1 = 0;
    hi2c1.Init.AddressingMode = I2C_ADDRESSINGMODE_7BIT;
    hi2c1.Init.DualAddressMode = I2C_DUALADDRESS_DISABLE;
    hi2c1.Init.OwnAddress2 = 0;
    hi2c1.Init.OwnAddress2Masks = I2C_OA2_NOMASK;
    hi2c1.Init.GeneralCallMode = I2C_GENERALCALL_DISABLE;
    hi2c1.Init.NoStretchMode = I2C_NOSTRETCH_DISABLE;

    HAL_I2C_Init(&hi2c1);
    HAL_I2CEx_ConfigAnalogFilter(&hi2c1, I2C_ANALOGFILTER_ENABLE);
    HAL_I2CEx_ConfigDigitalFilter(&hi2c1, 0);
}

static void MX_SAI1_Init(void) {
    hsai_BlockA1.Instance = SAI1_Block_A;
    hsai_BlockA1.Init.AudioMode = SAI_MODESLAVE_TX;
    hsai_BlockA1.Init.Synchro = SAI_SYNCHRONOUS;
    hsai_BlockA1.Init.OutputDrive = SAI_OUTPUTDRIVE_ENABLE;
    hsai_BlockA1.Init.FIFOThreshold = SAI_FIFOTHRESHOLD_HF;
    hsai_BlockA1.Init.SynchroExt = SAI_SYNCEXT_DISABLE;
    hsai_BlockA1.Init.MonoStereoMode = SAI_MONOMODE;
    hsai_BlockA1.Init.CompandingMode = SAI_NOCOMPANDING;
    hsai_BlockA1.Init.TriState = SAI_OUTPUT_NOTRELEASED;

    hsai_BlockB1.Instance = SAI1_Block_B;
    hsai_BlockB1.Init.AudioMode = SAI_MODESLAVE_RX;
    hsai_BlockB1.Init.Synchro = SAI_ASYNCHRONOUS;
    hsai_BlockB1.Init.OutputDrive = SAI_OUTPUTDRIVE_DISABLE;
    hsai_BlockB1.Init.FIFOThreshold = SAI_FIFOTHRESHOLD_HF;
    hsai_BlockB1.Init.SynchroExt = SAI_SYNCEXT_DISABLE;
    hsai_BlockB1.Init.MonoStereoMode = SAI_MONOMODE;
    hsai_BlockB1.Init.CompandingMode = SAI_NOCOMPANDING;
    hsai_BlockB1.Init.TriState = SAI_OUTPUT_NOTRELEASED;

    HAL_SAI_InitProtocol(&hsai_BlockA1, SAI_I2S_STANDARD, SAI_PROTOCOL_DATASIZE_16BIT, 2);
    HAL_SAI_InitProtocol(&hsai_BlockB1, SAI_I2S_STANDARD, SAI_PROTOCOL_DATASIZE_16BIT, 2);

    // Overwrite HAL Frame number with max9860 supported value
    hsai_BlockA1.Instance->FRCR &= ~SAI_xFRCR_FRL;
    hsai_BlockA1.Instance->FRCR |= 48U - 1U;

    hsai_BlockB1.Instance->FRCR &= ~SAI_xFRCR_FRL;
    hsai_BlockB1.Instance->FRCR |= 48U - 1U;
}

static void MX_TIM2_Init(void) {
    TIM_ClockConfigTypeDef sClockSourceConfig = {0};
    TIM_MasterConfigTypeDef sMasterConfig = {0};
    TIM_OC_InitTypeDef sConfigOC = {0};

    htim2.Instance = TIM2;
    htim2.Init.Prescaler = HAL_RCC_GetSysClockFreq() / 100000ULL;  // Count at 100khz
    htim2.Init.CounterMode = TIM_COUNTERMODE_UP;
    htim2.Init.Period = 100;  // Count up to 100 before reset. PWM freq is 100khz/100 = 1kHz
    htim2.Init.ClockDivision = TIM_CLOCKDIVISION_DIV1;
    htim2.Init.AutoReloadPreload = TIM_AUTORELOAD_PRELOAD_ENABLE;
    if (HAL_TIM_Base_Init(&htim2) != HAL_OK) {
        Error_Handler();
    }
    sClockSourceConfig.ClockSource = TIM_CLOCKSOURCE_INTERNAL;
    if (HAL_TIM_ConfigClockSource(&htim2, &sClockSourceConfig) != HAL_OK) {
        Error_Handler();
    }
    if (HAL_TIM_PWM_Init(&htim2) != HAL_OK) {
        Error_Handler();
    }
    sMasterConfig.MasterOutputTrigger = TIM_TRGO_RESET;
    sMasterConfig.MasterSlaveMode = TIM_MASTERSLAVEMODE_DISABLE;
    if (HAL_TIMEx_MasterConfigSynchronization(&htim2, &sMasterConfig) != HAL_OK) {
        Error_Handler();
    }
    sConfigOC.OCMode = TIM_OCMODE_PWM1;
    sConfigOC.Pulse = 0;
    sConfigOC.OCPolarity = TIM_OCPOLARITY_LOW;
    sConfigOC.OCFastMode = TIM_OCFAST_DISABLE;
    if (HAL_TIM_PWM_ConfigChannel(&htim2, &sConfigOC, TIM_CHANNEL_1) != HAL_OK) {
        Error_Handler();
    }
    HAL_TIM_MspPostInit(&htim2);
    HAL_TIM_PWM_Start(&htim2, TIM_CHANNEL_1);
}

static void MX_USART2_UART_Init(void) {
    huart2.Instance = USART2;
    huart2.Init.BaudRate = 115200;
    huart2.Init.WordLength = UART_WORDLENGTH_8B;
    huart2.Init.StopBits = UART_STOPBITS_1;
    huart2.Init.Parity = UART_PARITY_NONE;
    huart2.Init.Mode = UART_MODE_TX;
    huart2.Init.HwFlowCtl = UART_HWCONTROL_NONE;
    huart2.Init.OverSampling = UART_OVERSAMPLING_16;
    huart2.Init.OneBitSampling = UART_ONE_BIT_SAMPLE_DISABLE;
    huart2.Init.ClockPrescaler = UART_PRESCALER_DIV1;
    huart2.AdvancedInit.AdvFeatureInit = UART_ADVFEATURE_NO_INIT;

    HAL_UART_Init(&huart2);
    HAL_UARTEx_SetTxFifoThreshold(&huart2, UART_TXFIFO_THRESHOLD_1_8);
    HAL_UARTEx_SetRxFifoThreshold(&huart2, UART_RXFIFO_THRESHOLD_1_8);
    HAL_UARTEx_DisableFifoMode(&huart2);
}

static void MX_DMA_Init(void) {
    __HAL_RCC_DMAMUX1_CLK_ENABLE();
    __HAL_RCC_DMA1_CLK_ENABLE();

    HAL_NVIC_SetPriority(DMA1_Channel1_IRQn, 0, 0);
    HAL_NVIC_EnableIRQ(DMA1_Channel1_IRQn);
    HAL_NVIC_SetPriority(DMA1_Channel2_IRQn, 0, 0);
    HAL_NVIC_EnableIRQ(DMA1_Channel2_IRQn);
}

static void MX_GPIO_Init(void) {
    GPIO_InitTypeDef GPIO_InitStruct = {0};

    __HAL_RCC_GPIOA_CLK_ENABLE();
    __HAL_RCC_GPIOB_CLK_ENABLE();

    GPIO_InitStruct.Pin = MAX9860_IRQ_Pin;
    GPIO_InitStruct.Mode = GPIO_MODE_IT_RISING;
    GPIO_InitStruct.Pull = GPIO_PULLUP;
    HAL_GPIO_Init(MAX9860_IRQ_GPIO_Port, &GPIO_InitStruct);

    GPIO_InitStruct.Pin = BUTTON_Pin;
    GPIO_InitStruct.Mode = GPIO_MODE_INPUT;
    GPIO_InitStruct.Pull = GPIO_PULLDOWN;
    HAL_GPIO_Init(BUTTON_GPIO_Port, &GPIO_InitStruct);

    GPIO_InitStruct.Pin = MCO_MCLK_Pin;
    GPIO_InitStruct.Mode = GPIO_MODE_AF_PP;
    GPIO_InitStruct.Pull = GPIO_NOPULL;
    GPIO_InitStruct.Speed = GPIO_SPEED_FREQ_MEDIUM;
    GPIO_InitStruct.Alternate = GPIO_AF0_MCO;
    HAL_GPIO_Init(MCO_MCLK_GPIO_Port, &GPIO_InitStruct);

    HAL_NVIC_SetPriority(EXTI9_5_IRQn, 0, 0);
    HAL_NVIC_EnableIRQ(EXTI9_5_IRQn);
}

void Error_Handler(void) {
    while (1) {
        HAL_UART_Transmit(&huart2, (uint8_t *)"E\n", 2, 0xFFFF);
    }
    __disable_irq();
}
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

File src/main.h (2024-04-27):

// SPDX-License-Identifier: MIT
// SPDX-FileCopyrightText: 2024 Ryan Wendland

#pragma once

#ifdef __cplusplus
extern "C" {
#endif

#include "stm32g4xx_hal.h"

void io_npf_putc(int c, void *ctx);
void HAL_TIM_MspPostInit(TIM_HandleTypeDef *htim);
void Error_Handler(void);

#define LED_Pin GPIO_PIN_0
#define LED_GPIO_Port GPIOA
#define FS_LRCLK_Pin GPIO_PIN_4
#define FS_LRCLK_GPIO_Port GPIOA
#define MAX9860_IRQ_Pin GPIO_PIN_7
#define MAX9860_IRQ_GPIO_Port GPIOA
#define MAX9860_IRQ_EXTI_IRQn EXTI9_5_IRQn
#define BUTTON_Pin GPIO_PIN_0
#define BUTTON_GPIO_Port GPIOB
#define MCO_MCLK_Pin GPIO_PIN_8
#define MCO_MCLK_GPIO_Port GPIOA
#define SD_TX_Pin GPIO_PIN_10
#define SD_TX_GPIO_Port GPIOA
#define SCK_BCLK_Pin GPIO_PIN_3
#define SCK_BCLK_GPIO_Port GPIOB
#define SD_RX_Pin GPIO_PIN_5
#define SD_RX_GPIO_Port GPIOB

#ifdef __cplusplus
}
#endif

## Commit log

2024-03-29 Hardware: Initial Commit
    [21-0139I_T2444-4_MXM.step, 54-00298.step, CUI_DEVICES_MJ-3523-SMT-TR.step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]
2024-04-27 Hardware: Reduce locking tab
    [hawk.kicad_pcb]
2024-04-27 Add installation slot note
2024-04-27 kitspace: Seems it expects gerbers extracted, also missing summary in yaml
    [hawk-B_Cu.gbl, hawk-B_Mask.gbs, hawk-B_Paste.gbp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]
2024-04-27 Add note about PCB thickness
2024-04-28 Firmware: Flash on codec init fail
    [main.c]
2024-04-28 README: Add note about blinking LED on boot failure
2024-05-11 hardware: Tweak to TRRS footprint
    [hawk-B_Cu.gbl, hawk-B_Mask.gbs, hawk-B_Paste.gbp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]
2025-03-16 bom: Update switch to low N, without boss
    [bom.csv]
2025-03-16 README: Include direct link to Gerber View
